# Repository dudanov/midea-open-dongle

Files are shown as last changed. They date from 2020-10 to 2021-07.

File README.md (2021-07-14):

# midea-open-dongle

# This project is no longer developing. Please use the [iot-uni-dongle](https://github.com/dudanov/iot-uni-dongle) project.

An open project for a stick for air conditioners controlled by the Midea UART protocol.

A far from complete list of supported brands:
1. [Midea](https://www.midea.com/)
2. [Electrolux](https://www.electrolux.ru/)
3. [Qlima](https://www.qlima.com/)
4. [Artel](https://www.artelgroup.com/)
5. [Carrier](https://www.carrier.com/)
6. [Comfee](http://www.comfee-russia.ru/)
7. [Inventor](https://www.inventorairconditioner.com/)

Board dimensions: 49x20mm, antennas: + 7mm, USB connector: + 15mm, overall: 71x20mm.

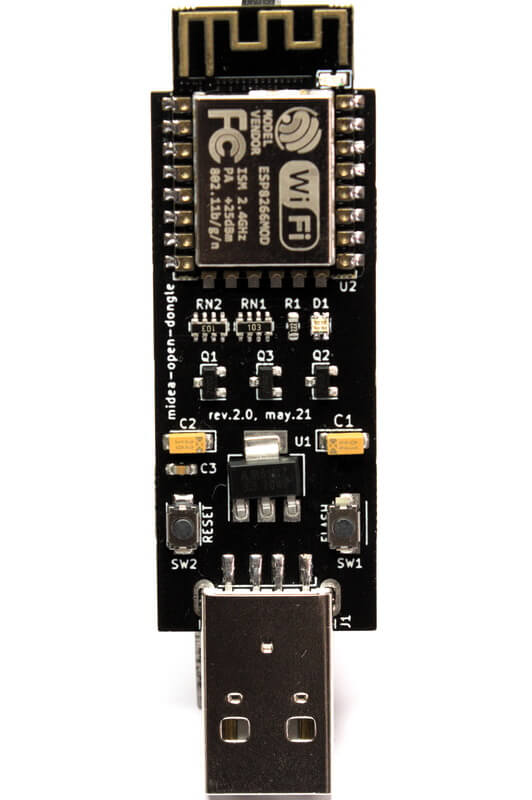
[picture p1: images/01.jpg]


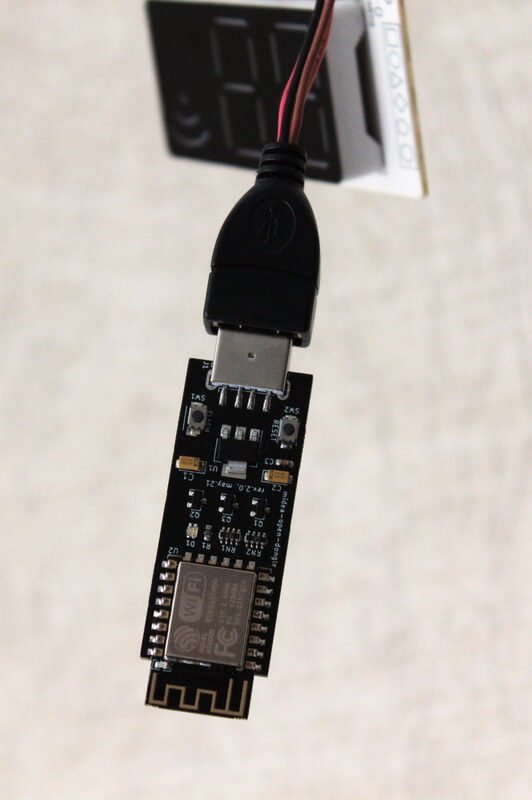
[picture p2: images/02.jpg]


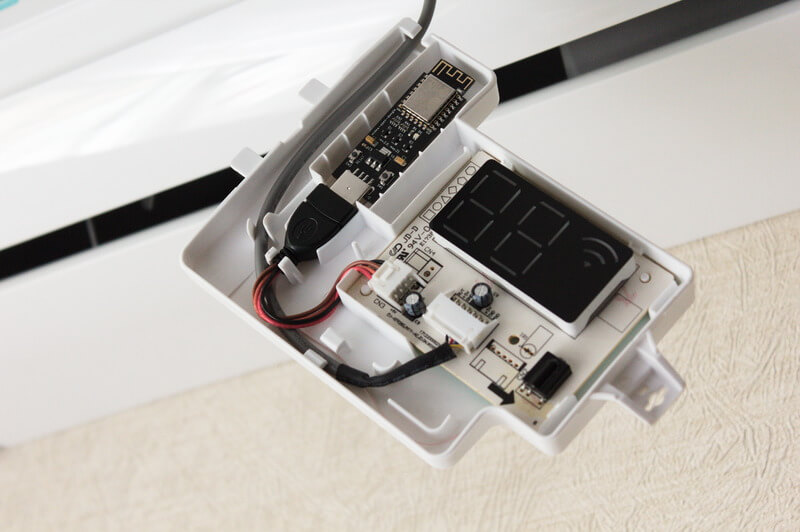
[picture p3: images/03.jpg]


Description of files:
* [schematic.pdf](schematic.pdf) - schematic diagram
* [gerber.zip](gerber.zip) - files for making a printed circuit board
* [bom.csv](bom.csv) - bill of materials
* [position.csv](position.csv) - CPL/POS file

The last 3 files can be used to order a stick from the [JLCPCB](https://jlcpcb.com) factory. All that remains is to solder the radio module and the USB connector yourself.

## Imitation of IR remote control commands

Due to the fact that not all capabilities are implemented in the UART protocol (for example, indication control and `FollowMe` feature), it is possible to simulate IR commands by supplying a demodulated signal to pin `GPIO13`.
To do this, connect the `IR_TSOP` pad located on the back of the stick and the output of the IR demodulator on the display board.
The pictures below show an example for a `TSOP1738` IR receiver.

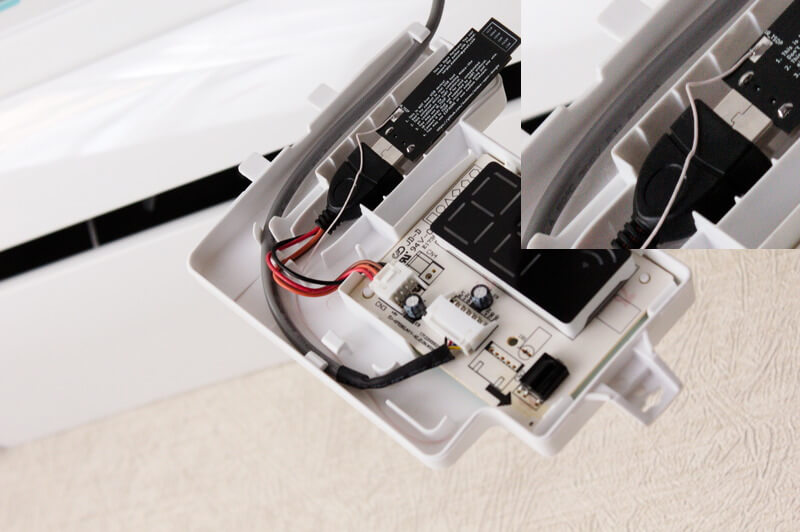
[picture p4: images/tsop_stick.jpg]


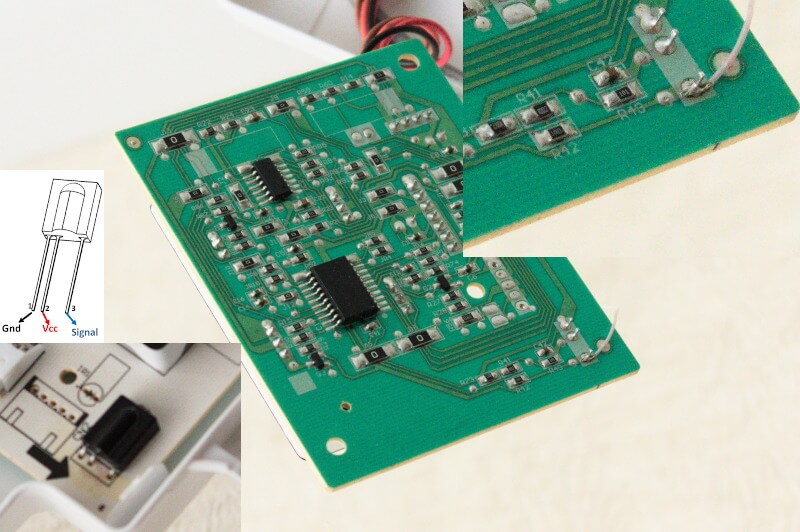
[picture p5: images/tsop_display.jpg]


## Frequently asked Questions:
> How can I tell if my air conditioner is supported or not?

*None 100% answer to the question. But there is a high probability of support if your air conditioner has a USB connector, a regular place for a stick, UART is used.*

> What firmware would you recommend?

*Initially, the stick was developed for [ESPHome](https://esphome.io) and [Home Assistant](https://www.home-assistant.io), but it is possible to write your own firmware for your tasks and needs if you have the appropriate skills.*

> Is it possible to purchase a ready-made stick?

*Yes, you can write me to my [Telegram](https://t.me/dudanov) or [e-mail](mailto:sergey.dudanov@gmail.com).*

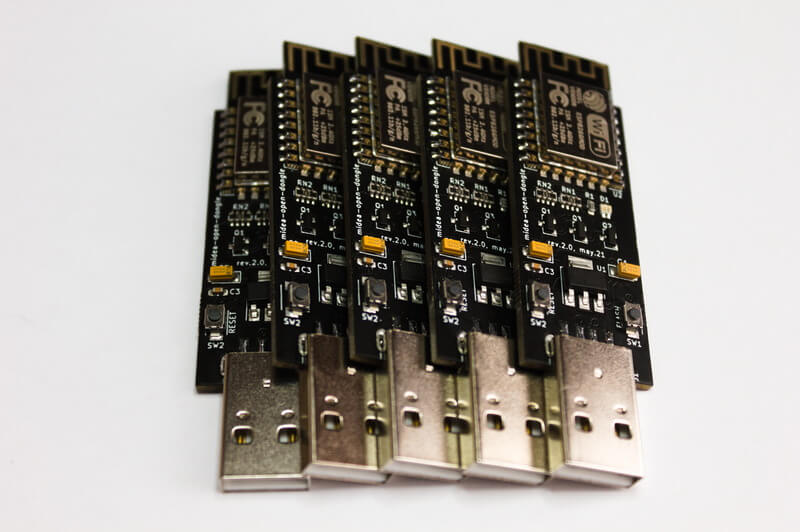
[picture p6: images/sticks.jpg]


If this project was useful to you, you can [buy me](https://paypal.me/dudan0v) a Cup of coffee :)

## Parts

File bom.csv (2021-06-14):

Comment | Designator | Footprint | LCSC
22uF | C1,C2 | Capacitor_Tantalum_SMD:CP_EIA-3216-18_Kemet-A | C129272
1nF | C3 | Capacitor_SMD:C_0603_1608Metric | C1588
KT-0603RG | D1 | project_components:KT-0603RG | C24477
AC connector | J1 | Connector_USB:USB_A_CNCTech_1001-011-01101_Horizontal
2N7002 | Q1,Q2,Q3 | Package_TO_SOT_SMD:SOT-23 | C8545
2.2K | R1 | Resistor_SMD:R_0603_1608Metric | C4190
10K | RN1,RN2 | Resistor_SMD:R_Array_Concave_4x0603 | C29718
FLASH | SW1 | project_components:TS-1088 | C720477
RESET | SW2 | project_components:TS-1088 | C720477
IR_TSOP | TP1 | project_components:IROUT
AMS1117-3.3 | U1 | Package_TO_SOT_SMD:SOT-223-3_TabPin2 | C6186
ESP-12F | U2 | project_components:ESP-12E

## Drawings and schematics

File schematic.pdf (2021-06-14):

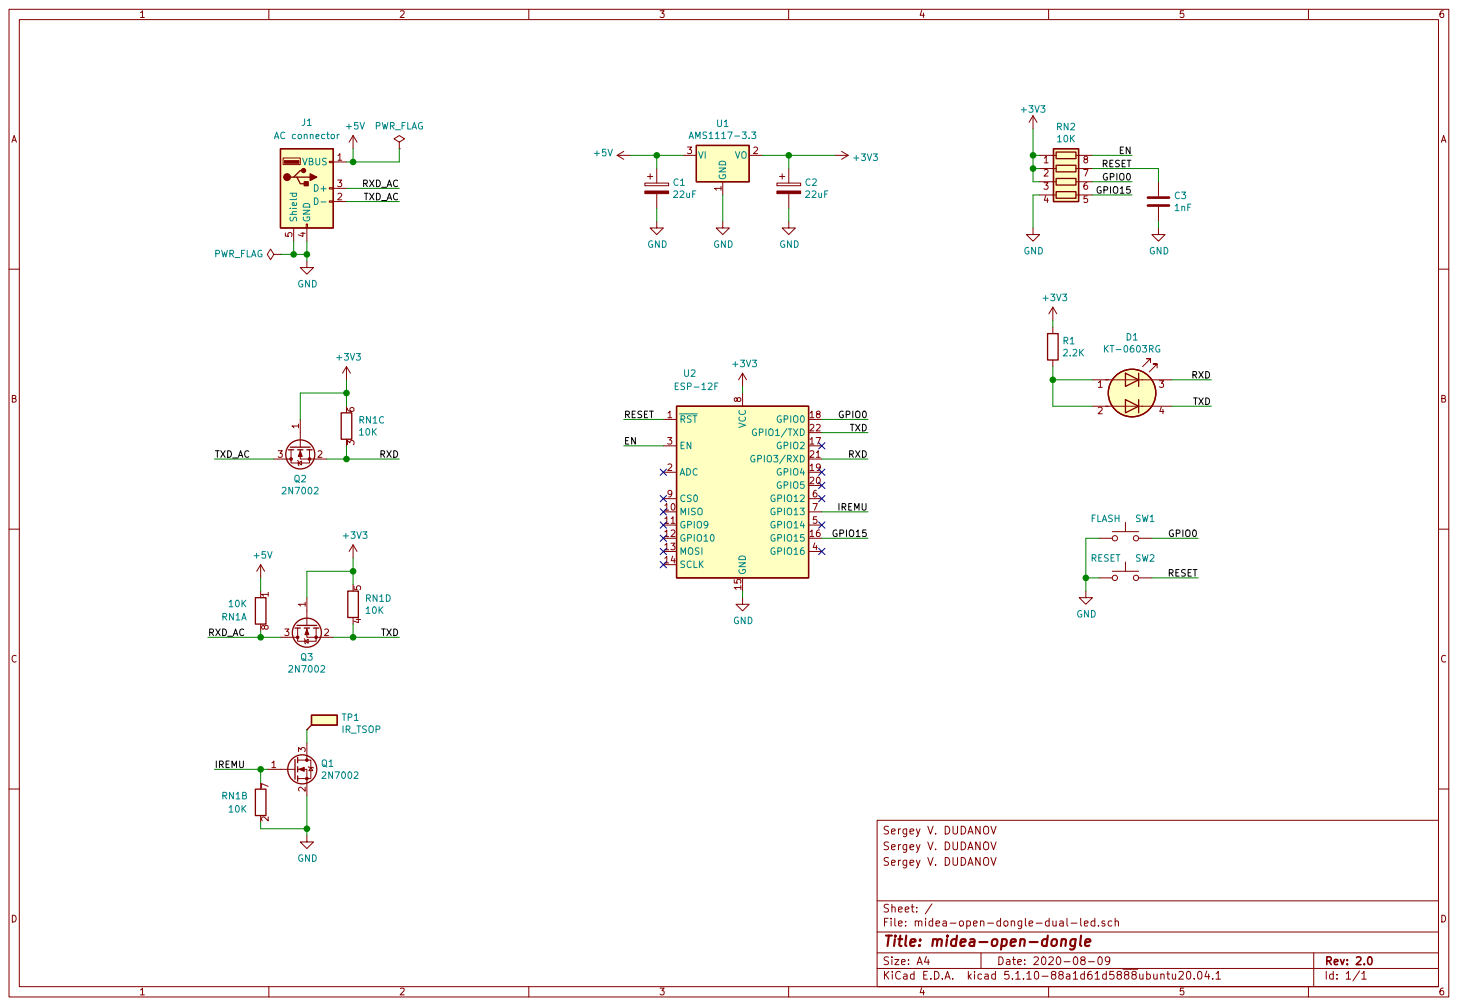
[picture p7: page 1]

1 VO 2 VI 3 U1 AMS1117-3.3 +3V3 RST 1 MISO 10 GPIO9 11 GPIO10 12 MOSI 13 SCLK 14 GND 15 GPIO15 16 GPIO2 17 GPIO0 18 GPIO4 19 ADC 2 GPIO5 20 GPIO3/RXD 21 GPIO1/TXD 22 EN 3 GPIO16 4 GPIO14 5 GPIO12 6 GPIO13 7 VCC

Sergey V. DUDANOV
File: midea-open-dongle-dual-led.sch Sheet: / Sergey V. DUDANOV

Id: 1/1 Title: midea-open-dongle

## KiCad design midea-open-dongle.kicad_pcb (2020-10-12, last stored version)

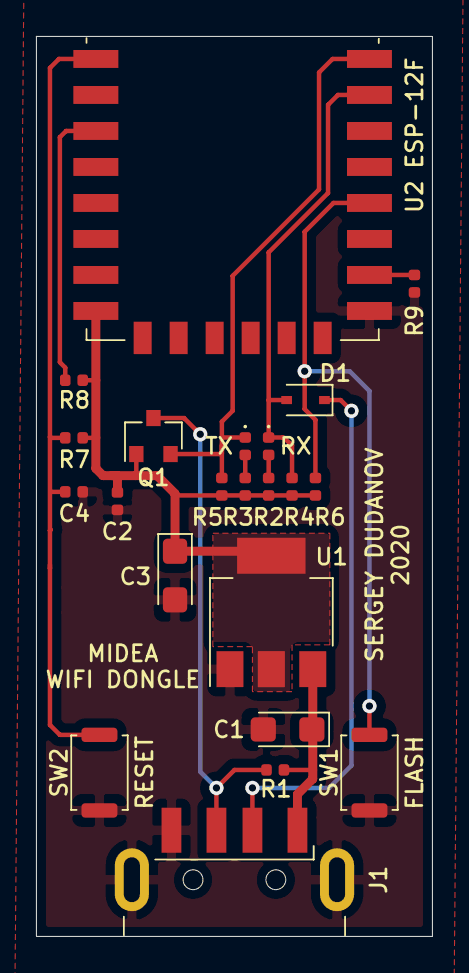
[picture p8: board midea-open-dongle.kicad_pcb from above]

Board: 2 copper layers, 22.0 x 50.0 mm, 22 parts (0 on the bottom side), 13 nets.

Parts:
C1: 10uF; CP_EIA-3216-10_Kemet-I
C2: 100nF; C_0402_1005Metric
C3: 47uF; CP_EIA-3216-10_Kemet-I
C4: 470pF; C_0402_1005Metric
D1: 1N5819; D_SOD-323
D2: RX; LED_0402_1005Metric
D3: TX; LED_0402_1005Metric
J1: USB Type A; USB_A_CNCTech_1001-011-01101_Horizontal
Q1: BSS138; SOT-23
R1, R4, R5, R6, R7, R8, R9: 10K; R_0402_1005Metric
R2, R3: 2.2K; R_0402_1005Metric
SW1: FLASH; SW_Push_SPST_NO_Alps_SKRK
SW2: RESET; SW_Push_SPST_NO_Alps_SKRK
U1: AMS1117-3.3; SOT-223-3_TabPin2
U2: ESP-12F; ESP-12E

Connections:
+3V3: C2.2, C3.1, Q1.1, R2.1, R3.1, R4.1, R5.1, R6.2, R7.2, R8.2, U1.2, U2.8
+5V: C1.1, J1.1, R1.1, U1.3
/EN: R8.1, U2.3
/GPIO0: R6.1, SW1.2, U2.18
/GPIO15: R9.1, U2.16
/RESET: C4.1, R7.1, SW2.2, U2.1
/RXD: D1.2, D2.1, R4.2, U2.21
/RXD_AC: J1.3, Q1.3, R1.2
/TXD: D3.1, Q1.2, R5.2, U2.22
/TXD_AC: D1.1, J1.2
GND: C1.2, C2.1, C3.2, C4.2, J1.4, J1.5, R9.2, SW1.1, SW2.1, U1.1, U2.15
unnamed: D2.2, R2.2
unnamed: D3.2, R3.2

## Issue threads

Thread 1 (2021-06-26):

Connections questions

Gio-dot, 2021-06-26:
Hi, thank you for your work. I would ask you few things to better understand your board:

1. Why did you use an usb connector on the board? It use a simple uart connection (not usb) so, why not use a normal 4 pin connector?
2. Can you show pins assignement on the aAC board side?
3. To flash esp you use an external usb to uart adapter, is this right?

Gio-dot, 2021-06-26:
Ok, i found answers reading more about midea component. Thank you
https://community.home-assistant.io/t/support-for-midea-a-c/265236

Closed 2021-06-26.

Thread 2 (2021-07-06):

Different ESP Module

marcojk, 2021-07-06:
Hi! Thanks for your work!
I've plenty of ESP01-S modules around and I'd like to use them in the dongle.
Could you share the schematics so that i can fit in the proper connector?

dudanov, 2021-07-06:
[schematics](https://github.com/dudanov/midea-open-dongle/blob/main/schematic.pdf)

marcojk, 2021-07-07:
Sorry, I meant the project file of Kicad or EasyEda; I'd like to maintain your pretty layout

dudanov, 2021-07-07:
[kicad.zip](https://github.com/dudanov/midea-open-dongle/files/6779372/kicad.zip)

Closed 2021-07-09.

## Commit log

2021-06-14 Update to rev2.0
    [midea-open-dongle-panelize.kicad_pcb, midea-open-dongle.kicad_pcb, midea-open-dongle.sch]
2021-06-14 Add BOM and POS files
    [bom.csv, position.csv]
